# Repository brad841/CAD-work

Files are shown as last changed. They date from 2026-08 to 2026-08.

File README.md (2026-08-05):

# Sonos Move 2 — 2.5 in tent pole mount

Suspended Move 2, over-centre wrap clamp into a 15° bayonet cradle. No adhesive,
no drilling, no tools, teardown under 30 s.

## Status

**Geometry complete for the core mount and Module B. Failure gauntlet passes.
Module A (drip canopy) is still blocked. Mass is 485 g against a 400 g budget.**

```bash
python3 -m venv .venv && .venv/bin/python -m pip install build123d

.venv/bin/python scripts/validate_params.py     # gate + bounds report
.venv/bin/python tests/test_gate0.py            # 69 checks
.venv/bin/python scripts/check_bayonet_fit.py   # 12 checks, tolerance both ways
.venv/bin/python scripts/check_clamp_fit.py     # 8 checks
.venv/bin/python scripts/assemble.py            # clash check + merged STEP
.venv/bin/python scripts/gauntlet.py            # failure critic
.venv/bin/python scripts/build_all.py           # all parts + mass (fails on budget)
```

All exit 0 except `build_all`, which fails on the mass budget — deliberately, see
below. Deliverables land in `out/`: STEP + STL per part, plus `assembly.step`.

## Gauntlet result

**PASS.** Weakest link: **lever ear bearing** in `clamp_shell_swing` at **1.65×**
on the derated allowable — 8.3× on the underlying material strength, since the
allowable already carries the 5× creep factor.

The gauntlet's one real idea is that **load duration picks the allowable**:

- **Sustained** members hold load for days at 55 °C. Creep governs: short-term
  strength knocked down for temperature and duration, then ÷5.
- **Transient** members are loaded only while a hand is on them — the lever while
  you close it, the hook during a knock. Yield governs, with ÷2.

Applying the creep allowable to the lever would demand a 3× heavier lever for a
load lasting four seconds. Applying the transient allowable to the link would be
dangerous. It caught one genuine violation during the mass pass: the detent pocket
left 1.20 mm of collar wall, under the 2.4 mm floor. `COLLAR_WALL` is now derived
from the pocket depth so it cannot drift again.

## Mass: 485 g against 400 g, and why I stopped there

Mass is not in your priority list — the four priorities are doesn't drop, doesn't
mar, survives an overnight, reads as a product — and "load path wins" is explicit.
So I did a real reduction pass (576 → 485 g) and then stopped rather than thin
anything the gauntlet checks.

What the pass actually did: band height 82 → 62.5 mm (it drives both shells *and*
both TPU liners, ~2.9 g per mm across four parts), tray floor from a solid plate to
a rib grid (192 → 87 g), hollow boom and root gusset, I-sectioned hook post, liner
base 3.0 → 2.4 mm.

Three honest routes to the remaining 85 g, in order of value:

1. **ASA instead of PETG** — removes the 1.174× wall multiplier outright. Worth
   roughly 60–70 g and it fixes the UV problem too. Needs an enclosure.
2. **Measure the two CoM numbers.** The boom arm is 148.9 mm because CoM is
   *bounded* 20 mm forward and 135 mm up. Real values are almost certainly kinder,
   and boom length cascades into band height, shells and liners.
3. Accept 485 g. Nothing about it is unsafe; it is 85 g of conservatism.

## What the unmeasured numbers cost

| Unknown | How it was handled |
|---|---|
| Pole OD | Designed as a **range** (62–65 mm) with a printed shim set. A shim only ever adds material, so guessing wrong thickens the stack rather than loosening the grip. `pole_gauge_coupon` measures it at install. |
| Handle recess ×4 | The hook stopped depending on it: 26 mm wide (any four-finger recess is wider), TPU nose that conforms to any lip radius, height set by the installer over 140–205 mm. |
| CoM ×2 | Bounded to the adverse corner of the speaker's own envelope. Legitimate because a rigid body's CoM is physically confined inside it — reality is kinder in every case. Costs ~20% extra moment. |
| Charging base ×6 | **Still blocks Module A.** No conservative direction exists: too small a canopy drips on 15 V indoor-rated electronics, too large fouls the bayonet. |

`scripts/validate_params.py` prints all 8 bounds in use with the safety argument
and the cost of each, every run, so a bound cannot quietly become a fact.

## Load path

Gravity does the work. The speaker sits upright **on** the tray and compresses into
the base contacts; the body is never clamped. Anti-tip engages the moulded rear
handle recess in **shear only**.

The load runs boom → pad → band → pole. **Neither the hinge pin nor the lever link
is in the suspended path** — they only close the band. That is why a failed lever
releases the *clamp* rather than dropping the speaker.

Secondary retention is independent: the tether's upper end chokes the **pole**
above the clamp, not the clamp, so it still catches with the clamp fully open.

| | |
|---|---|
| Suspended load | 30.9 N (3.15 kg) |
| Moment arm to bounded CoM | 148.9 mm |
| Overturning moment | 4.60 N·m |
| Band height | 62.5 mm |
| Required friction preload | 343 N (5× anti-slip, μ = 0.45) |
| Link tension | 172 N continuous → **steel, not printed** |
| Lever advantage | 4.46×, so 38 N of hand force |
| Pole contact pressure | **0.035 MPa** vs a 0.60 limit |
| Worst tip moment | 1.86 N·m at −20° |
| Bayonet stack, worst case | +0.55 / −0.15 mm |

## Documents

- `docs/GATE0_MEASUREMENT_PROTOCOL.md` — the numbers, and which still block
- `docs/HARDWARE_BOM.md` — every non-printed part, with grades and lengths
- `docs/PRINT_SHEET.md` — generated from live geometry: mass, orientation, why
- `docs/INSTALL_CARD.md` — two-motion install, one page
- `docs/TETHER_SPEC.md` — cable, shock numbers, and why it bypasses the clamp

## Two gates I cannot discharge here

**Physical gate.** Printing the pole-gauge and bayonet coupons and confirming fit
on the actual pole needs the printer and the pole in hand. The coupons are built
and are the first thing on the print sheet; the tolerance stack is *not* verified
until you run them.

**Aesthetic critic.** The brief asks for a blind A/B against unlabeled renders of
commercial mounts across five views. I cannot execute that honestly in this
environment: there is no renderer here, and I cannot view the commercial mount
images the comparison depends on. `out/assembly.step` opens in any viewer — that
judgement is yours, and I would rather hand you the model than fabricate a verdict.

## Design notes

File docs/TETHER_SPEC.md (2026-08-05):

# Tether spec — mandatory, independent secondary retention

The requirement is precise and it drives the whole design of this part: the tether
must catch the speaker **with the clamp fully open.**

That single clause rules out the obvious build. If both ends attach to the clamp,
then the failure where the shells release and slide down the pole takes the tether
with them. A clamp-to-cradle tether only covers a bayonet release; it does nothing
for a clamp release, which is the more consequential of the two.

## So the tether does not touch the clamp

```
        pole
         ||
    [====]  <-- cable's upper eye: a choked loop around the POLE,
         ||      200-300 mm ABOVE the clamp band
         ||
    [CLAMP]  <-- tether passes it, anchored to neither shell
         ||
      \  ||
       \ ||   <-- slack, gathered in the shell's keeper lug
        \||
      [CRADLE]  <-- lower eye shackles to the boom's tether lug
```

- **Upper end:** choked loop around the pole itself, above the clamp. Choked, not
  clipped: it must grip under load rather than slide.
- **Lower end:** M5 screw-gate shackle to the tether lug on `cradle_boom`.
- **Keeper:** the lug on `clamp_shell_fixed` gathers the slack so the cable cannot
  swing or get lost. It is a keeper, **not** a load path.

## Parts

| Item | Spec | Qty |
|---|---|---|
| Cable | 2 mm 7×7 stainless (316), ~1.9 kN minimum breaking load | 450 mm |
| Eyes | Swaged copper or aluminium thimble eye, both ends | 2 |
| Shackle | M5 stainless screw-gate, 250 kg WLL | 1 |
| Keeper | Nylon P-clip or the printed lug on the fixed shell | 1 |

## Numbers

Static hang is 30.9 N. A drop onto the tether is not static: with ~40 mm of slack
and no compliance, a 3.15 kg mass arrests at roughly 15–20× static, so call it
**600 N** at the peak. A 2 mm 7×7 stainless cable at ~1.9 kN gives about **3×** on
that shock, and the swaged eye is the weak point at roughly 80–90% of cable
strength.

Keep the slack short. Halving the slack halves the arrest energy, and the cable is
the only thing in the assembly that is not designed to be loaded at all in normal
use.

## What it does and does not cover

Covers: bayonet released or failed; clamp lever released; clamp slid down the pole;
any single printed part in the suspended path failing.

Does **not** cover: the pole itself coming down, or the speaker being lifted out of
the tray by hand while the cradle stays put. Neither is a mount failure.

## Inspect it

Steel cable fails visibly before it fails structurally. Before each use, look for
broken strands at the swages — that is where they always start.

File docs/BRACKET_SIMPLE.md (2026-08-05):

# Simple bracket — print, insert, bolt

**2 printed parts. 2 bolts. 2 inserts. No supports.**

Supersedes the over-centre/bayonet design, which is still in the repo (see
"Archived" at the bottom) but is not what you should print.

## Print

| Part | Mass | Orientation | Notes |
|---|---|---|---|
| `pole_bracket` | 299 g | **Saddle face DOWN on the bed** | The whole bracket: collar half, arm, saddle, backstop |
| `clamp_backer` | 56 g | Pole axis normal to the bed | Plain curved block |

**355 g total, one of each.** PETG. 0.4 mm nozzle, 0.2 mm layers, 4 perimeters,
40% infill. Print hot and slow — PETG's layer bond is what carries this.

Saddle-down is not a preference, it is what makes the part support-free: the
saddle floor becomes the first layer, the collar bore becomes a vertical hole with
nothing to bridge, and the arm, lip and backstop are all vertical walls. Bending
from the cantilevered speaker then runs parallel to the layers, so the interlayer
strength never governs. The only horizontal holes are the two 5.4 mm bolt bores.

Fits a 256 mm bed at 170 × 178 mm.

## Hardware

| Item | Spec | Qty |
|---|---|---|
| Heat-set inserts | M5 brass, 6.4 mm OD × 9.5 mm | 2 |
| Bolts | M5 × 25 mm socket cap, A2 stainless | 2 |
| Washers | **M5 penny/fender, 15 mm OD** | 2 |
| Pole tape | 2 mm adhesive EPDM or rubber, ~25 mm wide × 250 mm | 1 strip |

The washers are not optional. An M5 cap head bearing directly on PETG at 172 N
sits at 3.7 MPa — over the sustained allowable — and would slowly sink into the
flange until the clamp lost preload. A 15 mm washer drops that to 1.1 MPa.

The tape is what protects the rented pole. It also does real work: it lines the
bore so the clamp grips 60–66 mm, covering the whole 62–65 mm range with nothing
to measure and nothing to shim.

## Assemble

1. Melt the two M5 inserts into the pads on `pole_bracket` — the bores are cut
   0.05 mm under the insert OD so the brass bites melted plastic.
2. Line the bracket's bore and the backer's bore with the tape.
3. Put the bracket on the front of the pole, the backer behind it.
4. Two bolts, washers under the heads, from the back. Tighten alternately until
   it will not twist by hand. You need nowhere near M5's capacity — 172 N per
   bolt is finger-tight-plus.
5. Speaker in the saddle, back against the backstop.

Charging base sits in the saddle's open floor; the cable falls straight through.
That opening is why the base footprint never had to be measured.

## Numbers

| | |
|---|---|
| Load | 30.9 N (3.15 kg) |
| Moment about the pole | 3.38 N·m |
| Arm bending at the collar | 0.28 MPa — **11.2×** on the derated allowable |
| Bolt tension required | 172 N each (5× anti-slip, μ = 0.45) |
| Washer bearing | 1.12 MPa |
| Insert pull-out | 0.90 MPa vs 1.96 MPa interlayer |
| Pole contact pressure | 0.038 MPa vs a 0.60 powder-coat limit |
| Grip range | 60–66 mm |

Every margin is on the 5×-derated creep allowable, so 11.2× on the arm means
~56× on raw material strength. Verify with `scripts/check_bracket.py`.

## What this drops from the old design

Over-centre lever, steel link, 2 clevis pins, 2 R-clips, hinge pin, 2 retainers,
bayonet collar, spigot, 3 detent balls, 3 springs, pitch index plate, 2 pitch
pins, rear handle hook, TPU nose, 2 TPU liners, 3-piece shim set, pole gauge
coupon, 2 bayonet coupons.

**13 printed parts → 2. Level only, no pitch adjustment.**

It also deletes two whole unknowns: the pole OD (the clamp just closes on it) and
the four unpublished handle-recess dimensions (the speaker sits in a cup instead
of being hooked).

## Retargeting

Edit `SPEAKER_W` and `SPEAKER_D` in `params/bracket.py`. Every saddle dimension
derives from them. A round speaker like the Sonos One would want a circular
pocket rather than a rectangular one — that is a saddle-profile change, not a
parameter change.

## Archived

The over-centre design is still under `params/` and `parts/` (`clamp_shell_*`,
`bayonet_*`, `over_center_lever`, `cradle_*`, `tray`, `rear_handle_hook`) with its
own gauntlet at `scripts/gauntlet.py`. Kept for reference. Not the print target.

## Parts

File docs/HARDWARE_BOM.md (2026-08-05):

# Hardware BOM

Everything not printed. Quantities are per one complete mount.

Sizes derive from `params/` — if you change the pole range or the band height, the
pin lengths below change with it. Re-run `scripts/gauntlet.py`, which prints the
current values.

## Fasteners and pins

| # | Item | Spec | Qty | Notes |
|---|---|---|---|---|
| 1 | Hinge pin | M4 × 75 mm plain steel dowel, A2 stainless preferred | 1 | **Plain, not threaded.** A thread in a hinge bore chews the PETG boss every time the clamp opens. Band is 62.5 mm; 75 mm leaves ends to retain. |
| 2 | Hinge pin retainers | 4 mm E-clip or 1.6 mm split pin | 2 | One each end. Must be removable by hand — teardown is under 30 s, no tools. |
| 3 | Lever pivot pin | M5 × 45 mm clevis pin, steel | 1 | Through both lever ears (9 mm each) and the 20 mm blade gap. |
| 4 | Catch pin | M5 × 35 mm clevis pin, steel | 1 | Through the catch boss (19.8 mm) plus the link. |
| 5 | Clevis pin retainers | 5 mm R-clip | 2 | Hand-removable. |
| 6 | Collar bolts | M5 × 16 mm socket cap, A2 stainless | 4 | Into heat-set inserts on the clamp pad, 30 × 42 mm centres. |
| 7 | Heat-set inserts | M5 brass, 6.4 mm OD × 9.5 mm | 4 | Bores are cut 0.05 mm **under** insert OD so the brass bites melted plastic. |
| 8 | Pitch hinge pin | M6 × 55 mm clevis pin, steel | 1 | Double shear in the boom fork. |
| 9 | Pitch index pin | M5 × 55 mm clevis pin, steel | 1 | The part you pull to change pitch. R-clip, no tool. |
| 10 | Hook clamp bolts | M5 × 20 mm socket cap + nyloc | 2 | Clamp the hook post at the height you find. |
| 11 | Detent balls | 4 mm stainless ball | 3 | One per bayonet lug. |
| 12 | Detent springs | 4 mm OD × 6 mm free length compression, ~5 N | 3 | Pocket is 3.2 mm deep, so ~2.8 mm of crush. |
| 13 | Anti-slip pads | 22 mm dia × 1.5 mm EPDM or silicone, adhesive-backed | 4 | Sit in 1.2 mm recesses so they are proud by ~0.3 mm only. |

## Steel link — not a purchased part

| # | Item | Spec | Qty |
|---|---|---|---|
| 14 | Lever link | 3 mm mild steel plate, laser-cut from `out/lever_link.step` | 1 |

27.6 mm pin centres, 8 mm strap, two Ø5.12 mm bores. Deburr both bores — a sharp
steel edge will chew the M5 clevis pin and the PETG boss it works against.

Sized in steel because it holds **172 N continuously**. A printed PETG link at the
same duty reaches only ~1.5× over the 5×-derated allowable even at 8 × 10 mm, and
its pin bearing exceeds the sustained tensile allowable outright. Steel gives 21×
at 8 g. If you have no cutter, file it from 3 mm flat bar — it is two holes and a
rounded rectangle.

## Tether

See `docs/TETHER_SPEC.md`. Summary: 2 mm 7×7 stainless cable, 450 mm, two swaged
thimble eyes, one M5 stainless screw-gate shackle.

## Deliberately absent

- **No adhesive** anywhere structural. The TPU liner and hook nose are press fits
  so they stay replaceable.
- **No threadlocker.** The over-centre lever holds itself; nothing relies on a
  fastener staying torqued.
- **No thread cut into any printed part.** Every threaded joint goes into a brass
  heat-set insert or a nyloc nut.

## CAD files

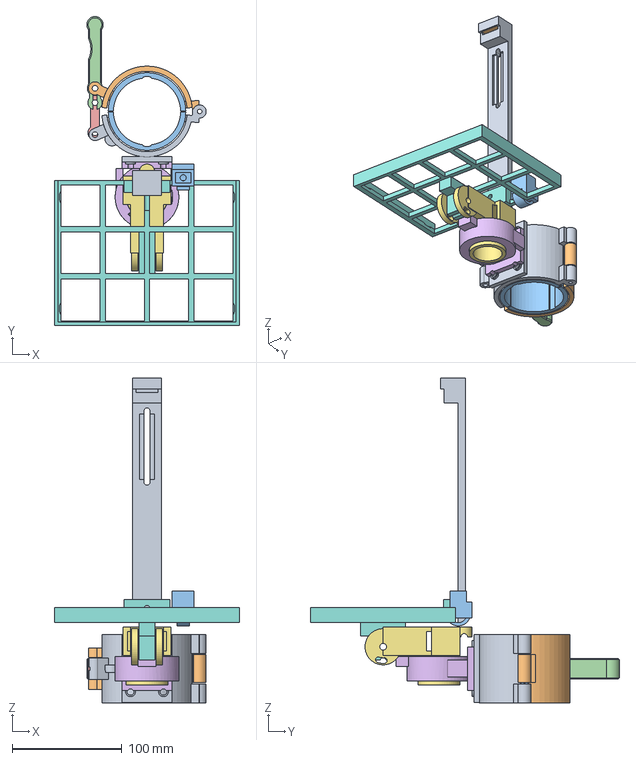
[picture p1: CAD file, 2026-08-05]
out/assembly.step
168.8 x 281.7 x 296.3 mm

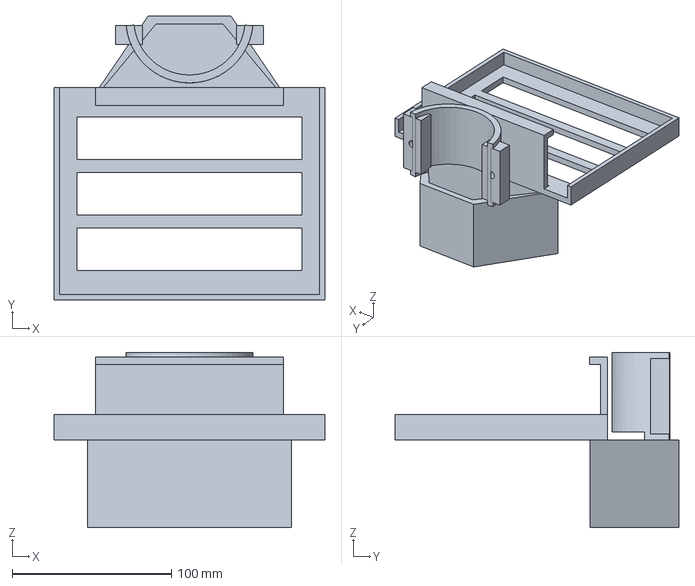
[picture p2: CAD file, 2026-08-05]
out/pole_bracket.step
170.0 x 178.2 x 110.0 mm

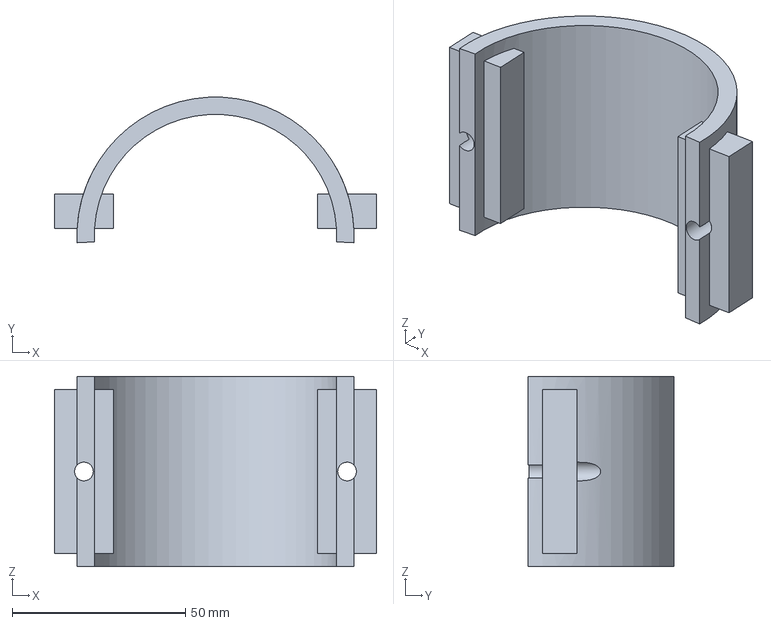
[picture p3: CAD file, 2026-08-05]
out/clamp_backer.step
93.0 x 42.0 x 55.0 mm

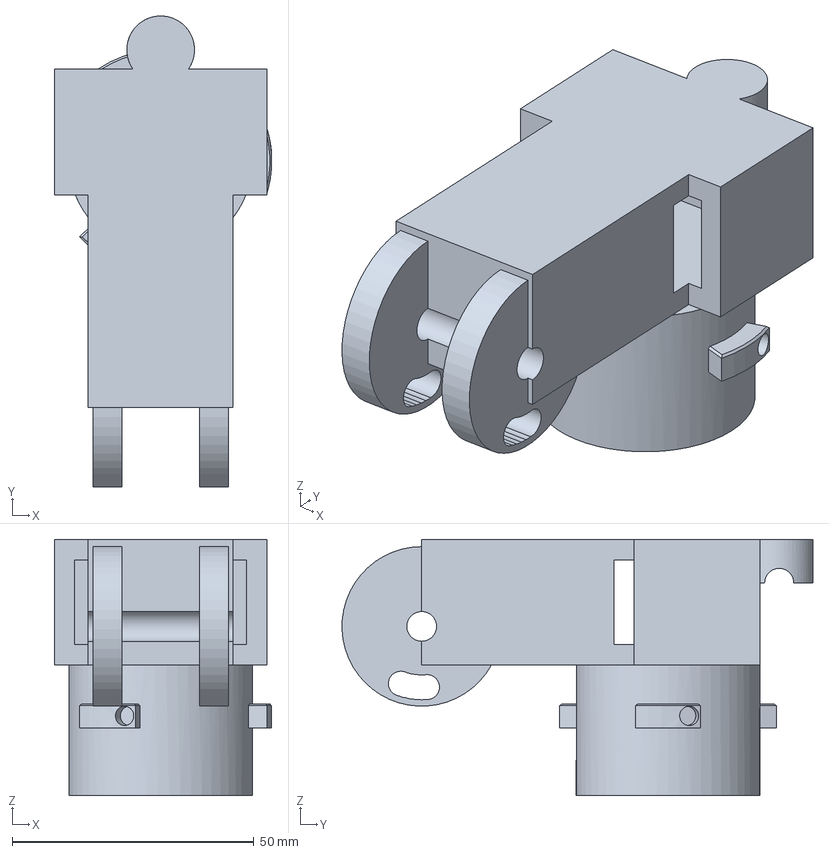
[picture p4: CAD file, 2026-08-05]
out/cradle_boom.step
45.0 x 97.4 x 53.0 mm

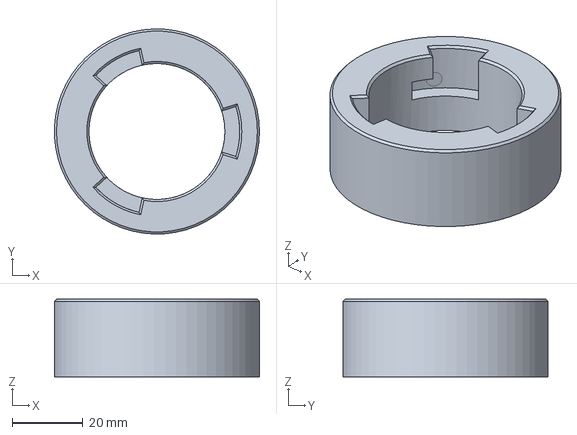
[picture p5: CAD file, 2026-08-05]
out/bayonet_coupon_female.step
58.1 x 58.1 x 22.0 mm

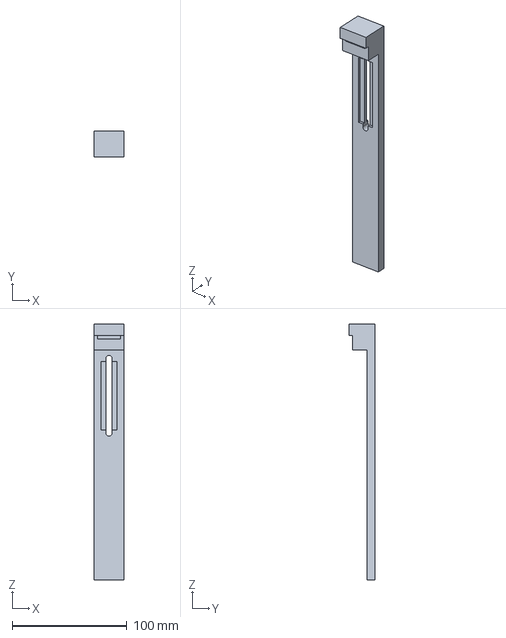
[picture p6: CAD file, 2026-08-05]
out/rear_handle_hook.step
26.0 x 23.0 x 223.0 mm

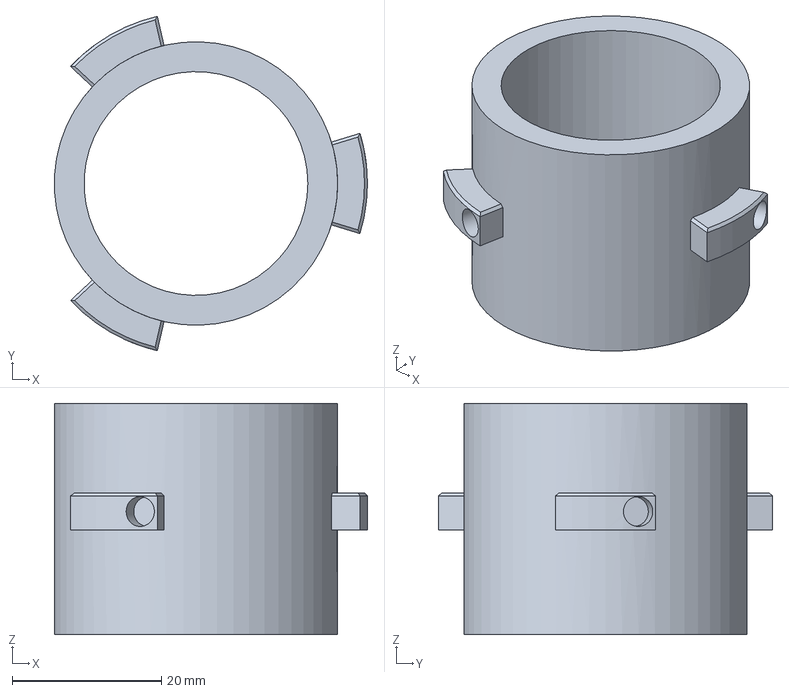
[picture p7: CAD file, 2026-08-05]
out/bayonet_coupon_male.step
42.0 x 44.8 x 31.0 mm

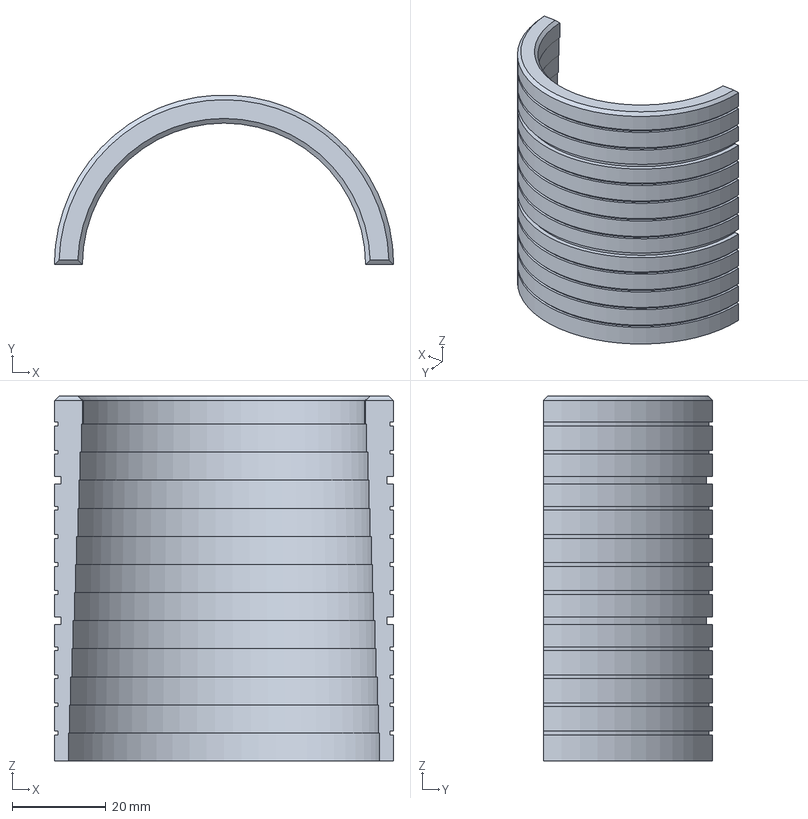
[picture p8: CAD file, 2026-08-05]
out/pole_gauge_coupon.step
72.5 x 36.2 x 78.0 mm

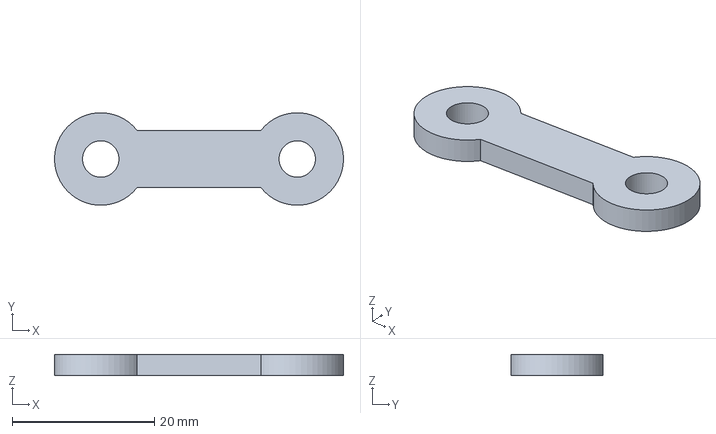
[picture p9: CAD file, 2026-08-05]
out/lever_link.step
40.6 x 13.0 x 3.00 mm

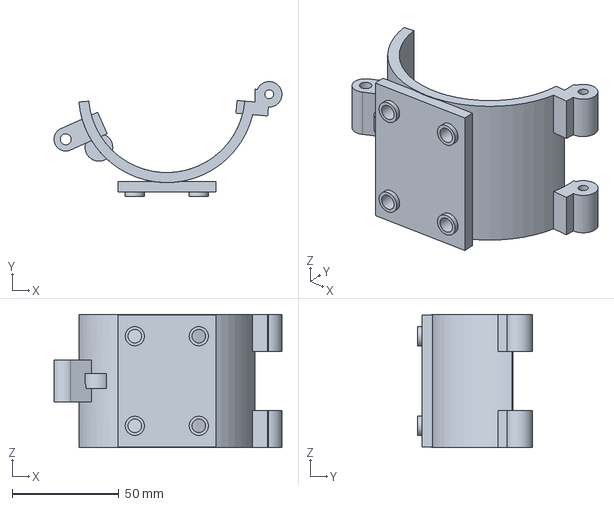
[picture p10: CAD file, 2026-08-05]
out/clamp_shell_fixed.step
106.9 x 53.9 x 62.5 mm

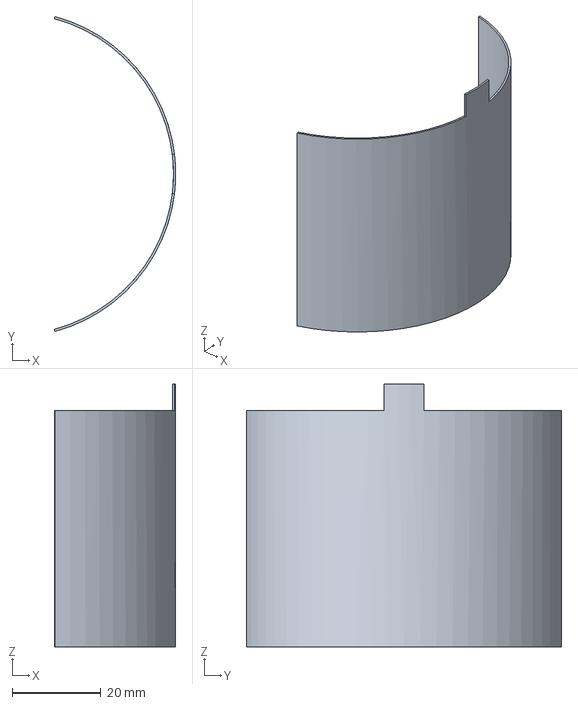
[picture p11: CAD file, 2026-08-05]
out/pole_shim_0p5mm.step
27.3 x 70.9 x 59.2 mm

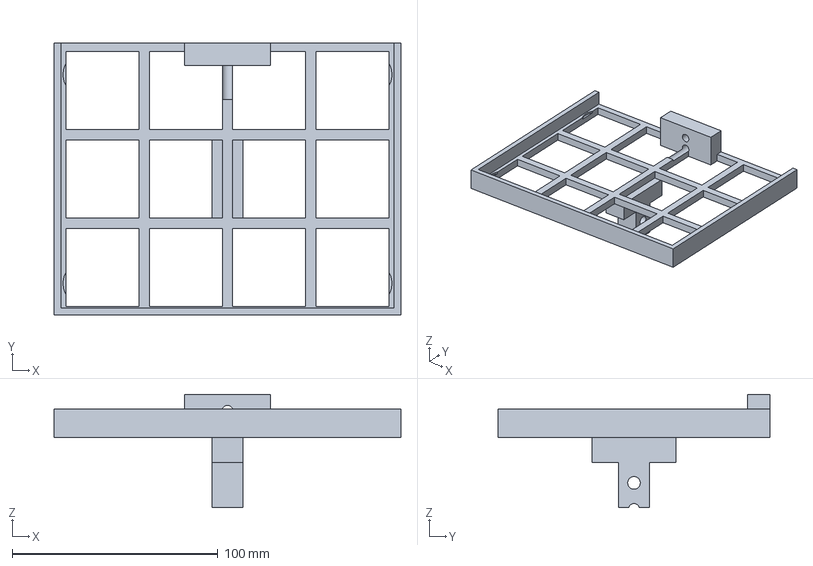
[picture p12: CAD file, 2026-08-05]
out/tray.step
168.8 x 132.4 x 55.0 mm

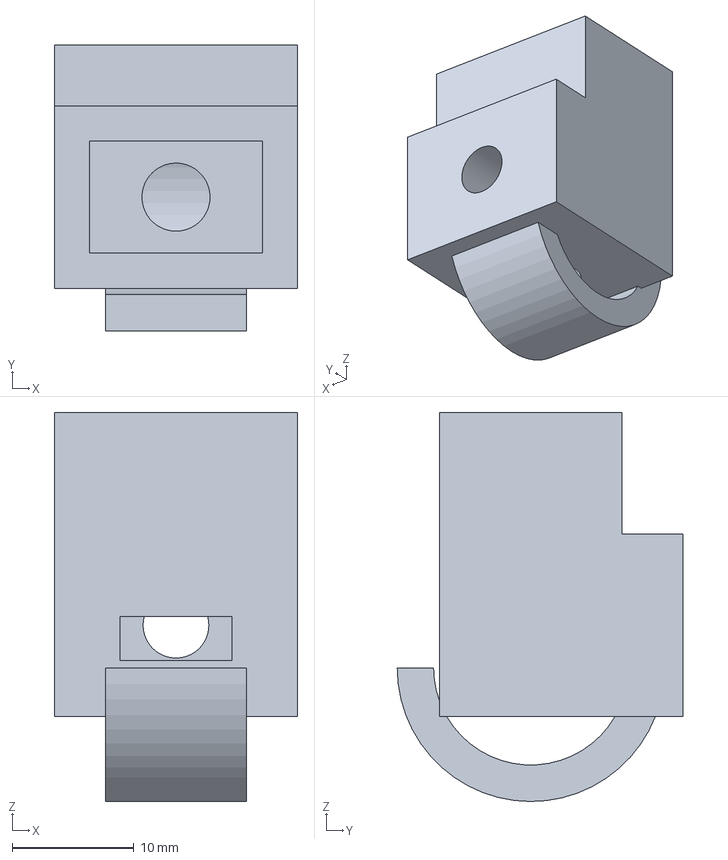
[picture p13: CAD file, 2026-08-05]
out/usbc_retainer.step
20.0 x 23.5 x 32.0 mm

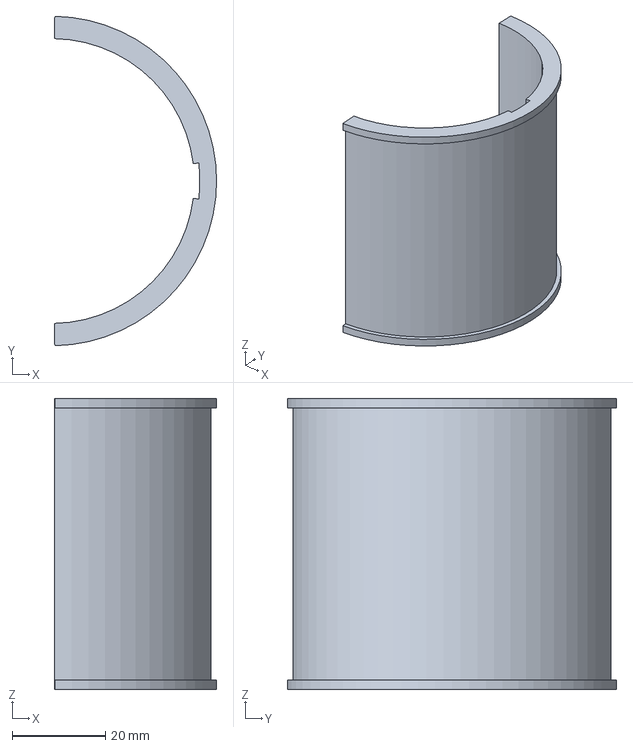
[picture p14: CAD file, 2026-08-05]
out/pole_liner.step
34.9 x 70.8 x 62.5 mm

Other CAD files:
out/over_center_lever.step
out/bayonet_collar.step
out/hook_nose.step
out/pole_shim_1p0mm.step
out/bayonet_collar.stl
out/bayonet_coupon_female.stl
out/bayonet_coupon_male.stl
out/clamp_backer.stl
out/clamp_shell_fixed.stl
out/clamp_shell_swing.step
out/clamp_shell_swing.stl
out/cradle_boom.stl
out/hook_nose.stl
out/lever_link.stl
out/over_center_lever.stl
out/pole_bracket.stl
out/pole_gauge_coupon.stl
out/pole_liner.stl
out/pole_shim_0p5mm.stl
out/pole_shim_1p0mm.stl
out/pole_shim_1p5mm.step
out/pole_shim_1p5mm.stl
out/rear_handle_hook.stl
out/tray.stl
out/usbc_retainer.stl

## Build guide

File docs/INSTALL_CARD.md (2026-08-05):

# Install card — two motions, nothing droppable

Print this and keep it with the parts. It fits on one side.

---

## Before you go: the pole gauge

Slide `pole_gauge_coupon` down the pole. It stops at the first step smaller than
the pole. **Count the ruler grooves up from the bottom** (wide groove every fifth)
to the step that stopped it — that reading picks your shim stack:

| Gauge reads | Shim stack per shell |
|---|---|
| 65.0 mm or larger | none |
| 64.0–64.5 mm | 0.5 mm |
| 63.0–63.5 mm | 1.0 mm |
| 62.0–62.5 mm | 1.5 mm |
| under 62.0 mm | outside the design range — do not fit |

Put the shims in the shell bore *behind* the TPU liner, not against the pole.

---

## Fit it — two motions

**Motion 1: wrap and throw the lever.**

1. Find the pole's weld seam with a fingernail. Rotate the clamp so the seam sits
   in the liner's centre groove — this is the one thing that protects the coating.
2. Open the shells, wrap the pole at your chosen height (speaker underside lands
   ~2100 mm above ground, so the band centre sits ~2000 mm).
3. Swing the lever closed. It goes over centre with a firm click and about 38 N —
   a comfortable one-hand pull. **It should get harder, then suddenly easier.** If
   it never gets easier you have not passed centre; if it never gets hard, add a
   shim.

**Motion 2: drop the cradle in and twist.**

4. Lower the cradle's spigot into the collar. It drops in on its own weight.
5. Rotate 15° until the detent clicks. You will feel it.

That is the whole install. Nothing was held while something else was found, and
nothing can be dropped in the grass.

**Then, before the speaker goes on:** choke the tether loop around the pole
200–300 mm above the clamp and shackle the other end to the cradle lug. Gather the
slack in the shell's keeper. See `docs/TETHER_SPEC.md`.

---

## Set the hook, once

The Move 2's handle recess dimensions are not published anywhere, so the hook is
adjustable and **you** set it:

6. Sit the speaker on the tray, pushed back against the hook post.
7. Slide the hook up or down until the TPU nose sits in the handle recess and bears
   up under the moulded lip. Snug, not tight — it is a shear stop, not a clamp.
8. Lock both M5 bolts. Mark the position with a pen; you will not have to find it
   again.

## Set the pitch

9. Pull the index pin, tilt to one of the six positions, push the pin back.

Positions are **−20, −15, −10, −5, 0, +5°**. There is no seventh hole: Sonos
permits 20° down and 5° up, and the plate has no position outside that. Inverted
use is prohibited and is not reachable.

---

## Teardown — under 30 s

Pull the index pin → twist the cradle 15° back → lift it out → unclip the tether →
throw the lever open → lift the clamp off the pole. No tools. Nothing left behind,
nothing marked.

---

## Two things that are not optional

- **The tether goes around the POLE, not the clamp.** Both ends on the clamp means
  a clamp release takes the tether with it.
- **The charging base is rated indoor only.** Module B (the USB-C retainer) is the
  weather-tolerant option and is what ships here. Do not put the factory base out
  overnight without the Module A canopy, which is not built yet.

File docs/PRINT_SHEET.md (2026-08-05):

# Print sheet

Material: **PETG**, with TPU 95A for the two compliant parts. Design temperature 55 C.

Print hot and slow. PETG's interlayer bond *is* the strength in the loaded
parts, and a fast cold PETG part is a delamination waiting for a hot
afternoon. 0.4 mm nozzle, 0.2 mm layers, 4 perimeters minimum on anything in
the load path, 40% infill or better in the clamp shells.

Orientation is a STRENGTH decision, not a convenience. Layer boundaries never
run normal to a principal tensile stress. Each choice and its reason:

| Part | Material | Qty | Mass | Orientation | Why |
|---|---|---|---|---|---|
| `clamp_shell_fixed` | PETG | 1 | 72.3 g | Pole axis normal to the plate. | Puts hoop tension in-plane. Standing it the other way would run the clamping load straight across layer boundaries. |
| `clamp_shell_swing` | PETG | 1 | 52.3 g | Pole axis normal to the plate. | Same hoop path as the fixed half. |
| `pole_liner` | TPU 95A | 2 | 27.4 g | Pole axis normal to the plate. | Compression only; orientation chosen for print reliability. |
| `over_center_lever` | PETG | 1 | 21.4 g | Lever flat on the plate, pivot axis vertical. | Bending is in-plane. This part is also visible jewelry, so the flat face against the plate becomes the show face. |
| `bayonet_collar` | PETG | 1 | 55.7 g | Bayonet axis normal to the plate. | Lug bearing faces come out as in-plane walls, and the slots print without bridging. |
| `cradle_boom` | PETG | 1 | 74.3 g | Long axis flat on the plate. Never standing up. | Axial tension and bending both in-plane. Standing it up would put the entire suspended load across layer boundaries — this is the single most orientation-critical part in the assembly. |
| `tray` | PETG | 1 | 80.7 g | Tray face down on the plate. | Show surface against glass, and tray bending stays in-plane. |
| `rear_handle_hook` | PETG | 1 | 54.3 g | Hook profile flat on the plate. | Loaded in shear across the hook throat; in-plane keeps the shear off layer boundaries. |
| `hook_nose` | TPU 95A | 1 | 1.2 g | Nose profile flat on the plate. | The compliant face that meets the handle lip. TPU because the lip radius is unpublished — the nose conforms to whatever is actually there instead of matching a number we never got. |
| `usbc_retainer` | PETG | 1 | 8.5 g | Plug axis flat on the plate, capture jaws vertical. | Module B. Carries no suspended load, only cable sway, so this is a stiffness and water-shedding part. Jaws vertical keeps the snap fingers' bending in-plane. |
| `pole_gauge_coupon` | PETG | 1 | 45.8 g | Axis normal to the plate — same as the clamp shells. | This coupon is only honest if printed the way the shells will be, so its bore reflects the same dimensional behaviour. |
| `bayonet_coupon_male` | PETG | 1 | 17.6 g | Bayonet axis normal to the plate. | Same as the production spigot, so the coupon tests the real joint. |
| `bayonet_coupon_female` | PETG | 1 | 38.5 g | Bayonet axis normal to the plate. | Same as the production collar. |

**Shims:** print `pole_shim_0p5mm`, `1p0mm` and `1p5mm` as one set. You will
use one or two of them, whichever the pole gauge selects. Curved face flat on
the plate, or a 0.5 mm shim will curl off the bed.

**Printed mount mass: 475 g**, against a 400 g budget — over by 75 g. The reason and the available trade are in the README; it is
not closed by thinning anything the gauntlet is checking.

## Print order — the coupons are a gate, not a suggestion

1. `pole_gauge_coupon` and both bayonet coupons. **Stop.** Fit them to the
   actual pole and to each other. Every clearance downstream depends on what
   these tell you about your machine.
2. Clamp group: both shells, both liners, the shim set, the lever.
3. Dock and cradle: collar, boom, tray, hook, TPU nose.
4. `usbc_retainer` (Module B).

## Supports

None needed on any part, by design: every unsupported overhang is under
50 deg and no bridge exceeds 12 mm.
If your slicer wants supports on a visible face, check the orientation against
the table before adding them — the fix is usually that the part is upside down.

## Not printed

`lever_link` is 3 mm steel. `out/lever_link.step` is a cutting profile, not a
print. See `docs/HARDWARE_BOM.md`.

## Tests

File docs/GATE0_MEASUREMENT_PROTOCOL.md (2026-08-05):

# Gate 0 — Measurement Protocol

> **Status update.** This document originally covered 21 blocking measurements.
> After the pole turned out to be unconfirmable and the Move 2's handle and CoM
> figures turned out to be genuinely unpublished, the gate was restructured.
> What is still required, and what is now optional:
>
> | Section | Status |
> |---|---|
> | 1. Pole OD ×6 + seam | **Superseded.** Designed as a range (62.0–65.0 mm) with a printed shim set. Do not measure; shim at install. |
> | 2. Pole wall + material | **Waived** by you as non-structural. Bounded to the thin/delicate case, which caps clamp pressure low and protects the pole. |
> | 3. Handle recess ×4 | **Optional.** Bounded conservatively; the hook is compliant and adjustable so it works without them. Measuring sheds ~20–30 % conservatism. |
> | 4. Charging base ×6 | **STILL REQUIRED.** Blocks Module A. No conservative direction exists — see below. |
> | 5. CoM ×2 | **Optional.** Bounded to the adverse corner of the speaker's envelope. Measuring sheds mass. |
>
> Sections 3 and 5 are worth doing if you have ten minutes and a caliper.
> Section 4 is the only one that blocks anything.
>
> **Why section 4 cannot be bounded:** every other unknown has a direction in
> which being wrong is safe. A canopy does not. Guess the footprint too small and
> water runs onto 15 V electronics that Sonos rates indoor only; guess it too
> large and the canopy fouls the bayonet and the silhouette. There is no
> conservative direction, so there is no honest bound, so it blocks.

This document is how to produce each number; `params/gate0.py` is where they go.

**Record everything in millimetres.** If you measure in inches, convert before
writing (`in × 25.4`), and write the converted number only. The validator traps
the obvious unit slips but it cannot catch all of them.

**Tools:** digital caliper (0.01 mm), steel rule, a length of string, your phone
camera, and a marker you can wipe off the pole. Nothing else.

---

## Why these 21 and not others

Each one changes geometry that cannot be fudged later:

| Group | What it decides |
|---|---|
| Pole OD ×6 | Shell bore, liner preload, whether the clamp grips an oval pole |
| Seam proud | Whether the liner straddles the weld or crushes it |
| Wall + material | How hard the clamp may squeeze before the rented pole dents |
| Handle recess ×4 | Whether the anti-tip hook engages in shear, or misses |
| Base ×6 | Drip canopy footprint, tray pocket, cable exit direction |
| CoM ×2 | Boom moment — multiplies into every structural number downstream |

---

## 1. Pole OD — six readings (3 heights × 2 axes)

A 2.5 in nominal pole measures anywhere from 62.0 to 65.0 mm in practice, and
it is rarely round. Averaging hides exactly the ovality the clamp has to grip
through, so we take six.

1. Decide where the clamp band will sit and mark it lightly — the speaker
   underside lands at **~2100 mm AGL**, so the band centre is roughly
   **2000 mm AGL**. Call this **MID**.
2. Mark **LO** 100 mm below MID and **HI** 100 mm above MID.
3. Find the weld seam. Run a fingernail up the tube — you will feel it before
   you see it. Mark its line down all three heights. This is **axis A**.
4. At each height take two caliper readings: **A** across the seam (jaws on the
   seam and directly opposite it), and **B** at 90° to it.
5. Close the caliper on the tube firmly enough to seat but not to compress the
   coating. Take each reading twice; if the pair disagrees by more than
   0.05 mm, take it again.

→ `POLE_OD_LO_A`, `POLE_OD_LO_B`, `POLE_OD_MID_A`, `POLE_OD_MID_B`,
  `POLE_OD_HI_A`, `POLE_OD_HI_B`

### Seam proud height

Lay the caliper's depth blade or a steel rule flat across the seam. Measure how
far the seam stands above the surrounding surface. Powder coat often buries it
to near-flush.

**If the seam is genuinely flush, write `0.0` — do not leave it unmeasured.**

→ `POLE_SEAM_PROUD`

## 2. Pole wall thickness and material

Wall thickness sets how hard the clamp may squeeze before the tube dents, and a
dented rented pole is priority-2 failure.

- **If an end is reachable:** caliper the wall directly at the tube end.
- **If not:** measure OD, then find the manufacturer's spec for the pole model.
  A typical 2.5 in steel tent pole runs 1.5–2.0 mm.
- **Last resort:** tap it. A ring means thin wall (<1.5 mm) and the clamp
  pressure needs to stay low; a dull thud means thicker.

Material matters because it sets what the liner is protecting: powder coat
scratches and chips, bare aluminium galls, galvanising is tougher than both.

→ `POLE_WALL_T`, `POLE_MATERIAL` (`'steel-powdercoat'`, `'steel-galv'`,
  `'aluminium-anodised'`, `'aluminium-bare'`)

## 3. Move 2 rear handle recess — four readings

This is the only place the mount touches the speaker other than the tray, and
it carries the anti-tip load **in shear**. Measure the real moulding, not the
press photos.

Stand the speaker upright on a flat table. The base plane is your Z datum.

1. **`HANDLE_RECESS_W`** — clear width of the recess opening at its widest.
   Caliper jaws inside the opening, spanning left to right.
2. **`HANDLE_RECESS_D`** — how far the recess cuts into the rear face. Caliper
   depth blade at the deepest point, referencing the outer rear surface.
3. **`HANDLE_LIP_R`** — radius of the moulded lip the hook will bear against.
   Use radius gauges if you have them; otherwise photograph the lip in profile
   against a rule and measure off the photo. **Round down**, never up: too small
   a modelled radius means the hook sits proud, too large means it rocks.
4. **`HANDLE_LIP_H_ABOVE_BASE`** — from the table surface up to the
   **load-bearing underside** of the lip, i.e. the face the hook pushes up
   against. Not the top of the opening. This one decides whether the hook
   engages at all.

Photograph all four with the caliper in frame. If a number later looks wrong,
the photo settles it without re-renting the pole.

## 4. Charging base — six readings

The base goes into Module A **unmodified**. It is rated indoor only, so the
canopy that keeps water off it is dimensioned entirely from these.

1. **`BASE_FOOTPRINT_X`** / **`BASE_FOOTPRINT_Y`** — outer footprint of the
   base where it meets a table. Left-right, then front-back. Include any rubber
   feet or flare at the bottom edge — the canopy overhangs the widest point.
2. **`BASE_HEIGHT`** — from the surface it sits on to the face the speaker's
   underside contacts.
3. **`BASE_PAD_OFFSET_X`** / **`BASE_PAD_OFFSET_Y`** — the charging contact pad
   is usually not centred. Measure from the footprint centre to the pad centre.
   Sign convention: **+X to the right, +Y aft (away from the speaker front)**.
   Write `0.0` for an axis where it genuinely is centred.
4. **`BASE_CABLE_EXIT`** — which way the USB-C cable leaves the base as it sits:
   `'aft'`, `'port'`, `'starboard'`, or `'under'`. This sets which way the drip
   loop runs and where the canopy drain goes. Getting it wrong routes water
   along the cable straight into the electronics.

## 5. Centre of mass — with the base installed

The number with the most leverage in the whole file. It multiplies against the
boom length to produce the overturning moment, which sizes the clamp, which
sizes the shells. A 15 mm error here propagates into every structural part.

**String-hang method — two orientations, intersect:**

1. Install the base on the speaker as it will actually hang. Tape it if needed
   so it cannot shift.
2. Tie a string loop around the assembly and hang it so it swings free. A body
   hanging from a single point always settles with its CoM directly below that
   point.
3. Photograph it **square-on**, camera level, no perspective tilt. The string
   line continued down through the body is one CoM line.
4. Re-hang from a clearly different point — rotate roughly 90° about the
   speaker's long axis. Photograph square-on again.
5. Overlay the two photos, extend both string lines, and mark where they cross.
   That intersection is the CoM.
6. Measure its position off the photo, scaled against a known dimension in
   frame. Use the verified **241 mm height** or **160 mm width** as your scale
   reference.

Report as offsets from the **speaker's base plane centre**:

- **`COM_OFFSET_Y`** — horizontal, **+ aft toward the pole**
- **`COM_OFFSET_Z`** — vertical, above the base plane

Sanity check before you write them: for a 241 mm speaker with a heavy driver
and battery low down, expect `COM_OFFSET_Z` somewhere around 95–125 mm. If your
number lands outside 30–200 mm the validator will reject it.

---

## Filling it in

Open `params/gate0.py`. Replace each `UNMEASURED(...)` call with the number:

```python
# before
POLE_OD_MID_A = UNMEASURED("POLE_OD_MID_A", "pole OD at clamp band centre, ...")

# after
POLE_OD_MID_A = 63.42
```

Strings for the two categorical fields:

```python
POLE_MATERIAL = "steel-powdercoat"
BASE_CABLE_EXIT = "aft"
```

Then run:

```bash
.venv/bin/python scripts/validate_params.py
```

- **exit 1** — still missing fields, it names them
- **exit 2** — all present but something is implausible, it says which and why
- **exit 0** — Gate 0 closed, geometry generation permitted

---

## If a measurement is genuinely unobtainable

Do not guess it into the file. Say which one and why, and it gets handled
explicitly — either the design changes so it stops mattering, or it becomes a
declared assumption recorded in the file with a comment, so the risk is visible
instead of buried in a plausible-looking number.

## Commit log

2026-08-05 Gate 0 scaffolding: enforced measurement gate, params spine, protocol
    Sets up the parametric foundation for the Move 2 pole mount. No geometry —
    Gate 0 requires 21 measured numbers that do not exist yet, and the gate is
    enforced in code rather than by convention.
    - params/gate0.py: the 21 measured inputs, each an Unmeasured sentinel that
    raises on any arithmetic, comparison, or cast. A generator cannot compute
    a slightly-wrong solid from a guessed pole diameter; it raises and names
    the field. This is the only file to edit when the pole changes.
    - params/clearances.py: one named variable per mating pair, with the reason
    each has its value. No hardcoded gaps elsewhere. VERIFY_BEFORE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
2026-08-05 Restructure the gate: measured / bounded / blocking, PETG, pole as a range
    The pole cannot be confirmed before the build and the Move 2's handle and CoM
    figures are not published anywhere. A gate that demands 21 measurements or
    nothing would have stalled indefinitely, so it now sorts numbers into three
    kinds and only blocks on the one where no guess can be made safe.
    MEASURED a real caliper reading
    BOUNDED a conservative substitute, chosen so being wrong makes the mount
    stronger or looser — never weaker or tighter. Each records why it
    is safe and what the conservatism costs. Arithmetic allowed, but
    all 8 are printed on every validator run so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
2026-08-05 Geometry: physical-gate coupons, bayonet interface, virtual fit check
    First geometry. Coupons before anything else, because they are the physical
    gate and nothing downstream is worth printing until they fit the real pole.
    - parts/_base.py: export refuses to write a solid that fails validation, so
    "generator exited 0" and "solid is sound" are the same statement. Checks
    OCC validity, positive volume, exactly one solid, valid shells.
    - parts/pole_gauge_coupon.py: measures the pole for us at install time. A 180
    deg half-shell whose bore steps 0.5 mm across the design range plus 1.5 mm
    margin either side. Slide it down, it stops at the first step smaller than
    the pole; the last step th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
    [bayonet_coupon_female.step, bayonet_coupon_female.stl, bayonet_coupon_male.step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]
2026-08-05 Geometry: pole interface — liner, shim set, both clamp shells
    The load-bearing half of the clamp. Layout lives in params/clamp.py so neither
    shell owns the split: the boom exits at 270 deg on the FIXED shell, so the
    suspended load runs boom -> pad -> band -> pole without passing through the
    hinge pin or the lever link. Neither mechanism is in the suspended path, which
    is why a failed lever releases the clamp rather than dropping the speaker.
    - params/clamp.py: the angular plan. Hinge at 0 deg, lever at 180, boom at 270,
    each shell wrapping 170 deg.
    - parts/pole_liner.py: TPU, the only thing touching the rented pole. Wraps
    further than the shell so the compliant edge meets the pole at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
    [bayonet_coupon_female.step, bayonet_coupon_male.step, clamp_shell_fixed.step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]
2026-08-05 Complete the core mount: mechanism, dock, cradle, gauntlet, deliverables
    Finishes geometry for everything except Module A. 12 bodies place without a
    clash, the merged assembly exports, and the failure gauntlet passes.
    New parts: over_center_lever, lever_link (steel), bayonet_collar, cradle_boom,
    tray, rear_handle_hook, hook_nose, usbc_retainer (Module B). Shared builders in
    parts/_bayonet.py so the coupons and the production collar/spigot are the SAME
    code — a coupon that fits proves the real joint fits.
    scripts/gauntlet.py is the failure critic: every loaded member with its section,
    stress, allowable and margin. Its central idea is that LOAD DURATION picks the
    allowable — creep with 5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
    [assembly.step, bayonet_collar.step, bayonet_collar.stl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]
2026-08-05 Simplify to a 2-part bolted bracket: print, insert, bolt
    The over-centre/bayonet design was over-built for the job. 13 printed parts, a
    steel link, clevis pins, R-clips, detent balls, springs, a pitch index and a
    gauge-plus-shim system to handle the unconfirmed pole. Replaced with a bolted
    split clamp on M5 heat-set inserts, per the Monzlteck-style inspiration.
    pole_bracket 299 g collar half + splayed arm + saddle + backstop, one solid
    clamp_backer 56 g plain curved block
    2 printed parts, 2 M5 bolts, 2 inserts, 2 penny washers, a strip of rubber tape.
    No supports. Fits a 256 mm bed. All checks pass at 11.2x on the arm.
    Two unknowns delete themselves as a side effect:
    - Pole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
    [clamp_backer.step, clamp_backer.stl, pole_bracket.step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]
